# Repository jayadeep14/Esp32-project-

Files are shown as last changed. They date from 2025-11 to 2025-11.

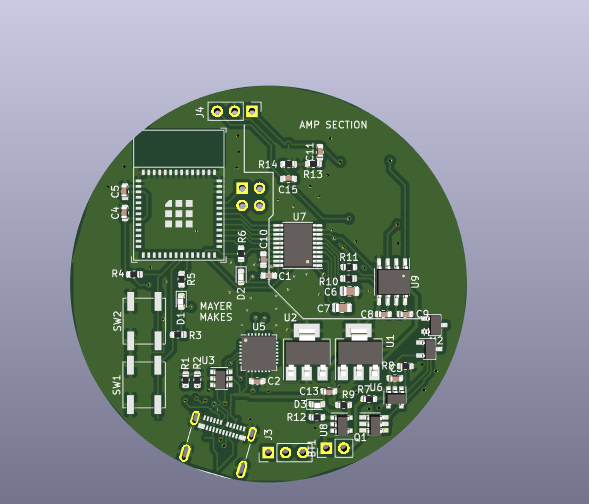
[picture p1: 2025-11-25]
Screenshot from 2025-11-24 19-12-08.png

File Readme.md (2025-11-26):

# ESP32 Bluetooth speaker



## Custom ESP32 Bluetooth speaker 
Creating a custom bluetooth speaker using esp32.Esp32 for bluetooth connectivity , a DAC (Digital-to-Analog Converter) for audio quality, potentially an amplifier, and a battery with a charging circuit.





[Bluetooth speaker case file](https://drive.google.com/file/d/19m-uVqZYdgPSqDJQQgZzTC6ExRgvEs1T/view?usp=drivesdk)

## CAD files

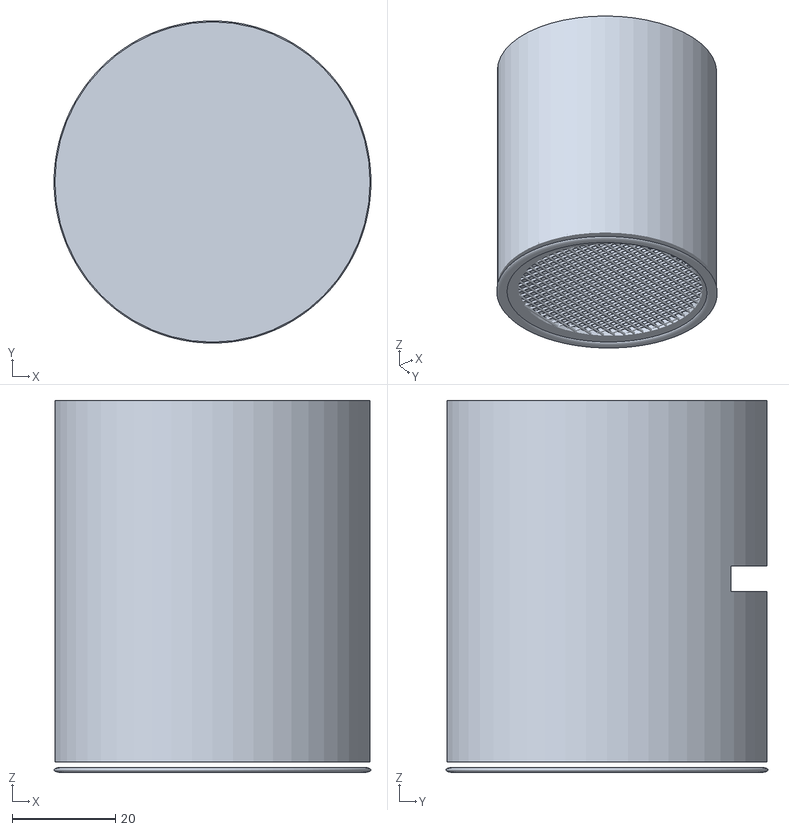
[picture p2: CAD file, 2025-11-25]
base.stl
61.3 x 62.3 x 72.0

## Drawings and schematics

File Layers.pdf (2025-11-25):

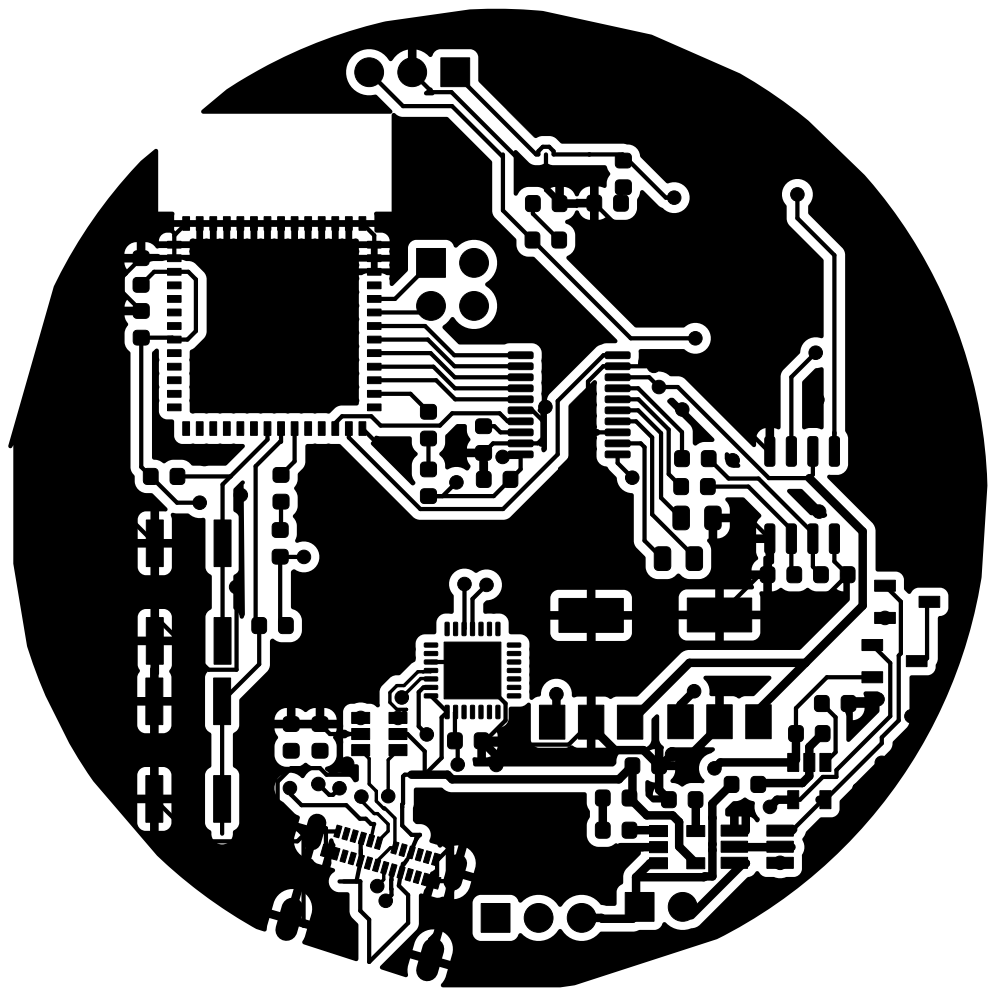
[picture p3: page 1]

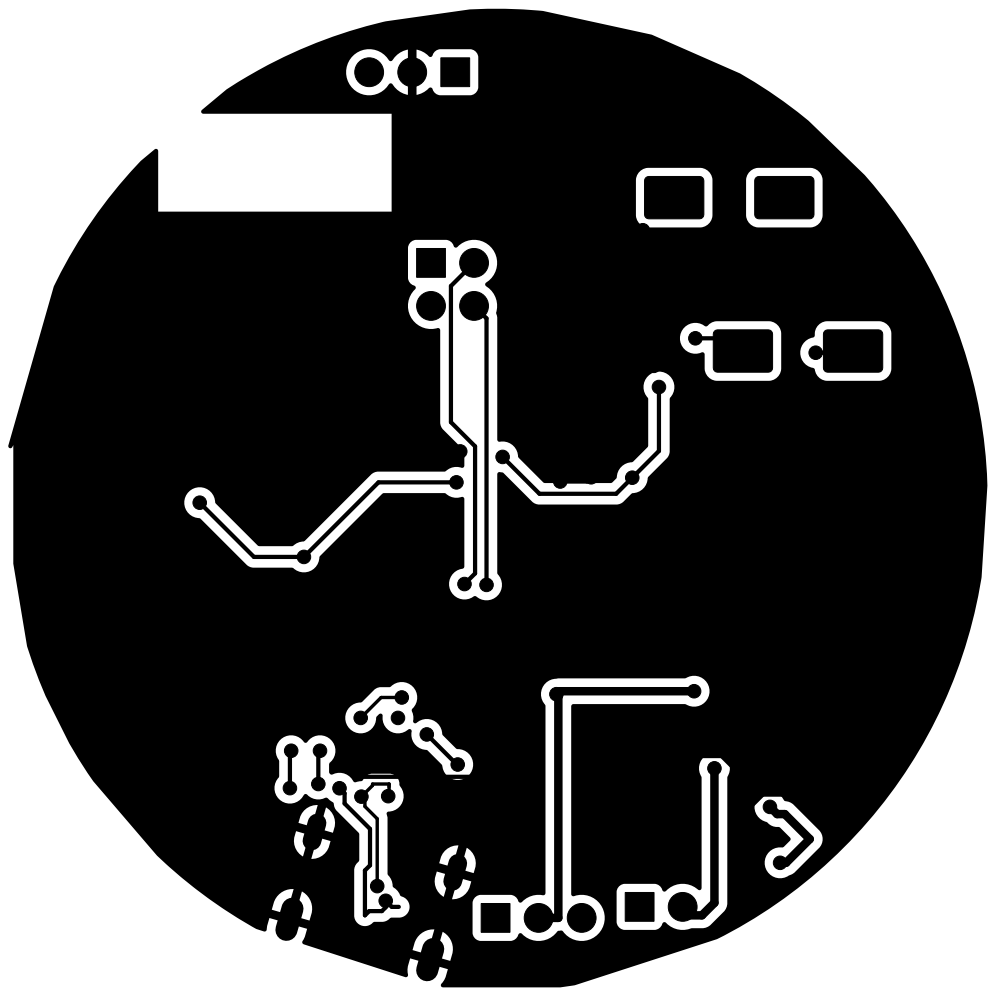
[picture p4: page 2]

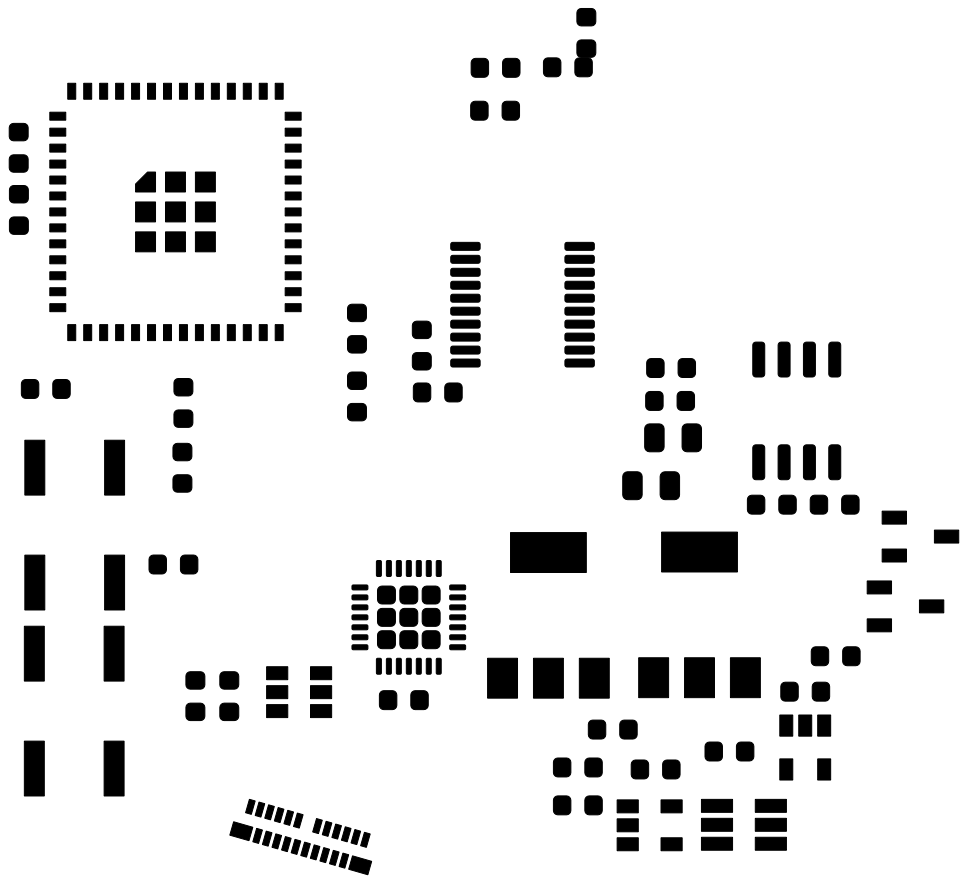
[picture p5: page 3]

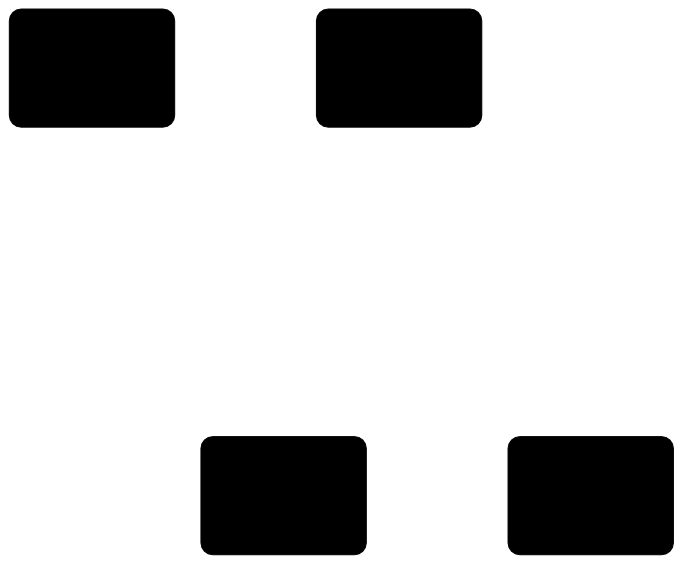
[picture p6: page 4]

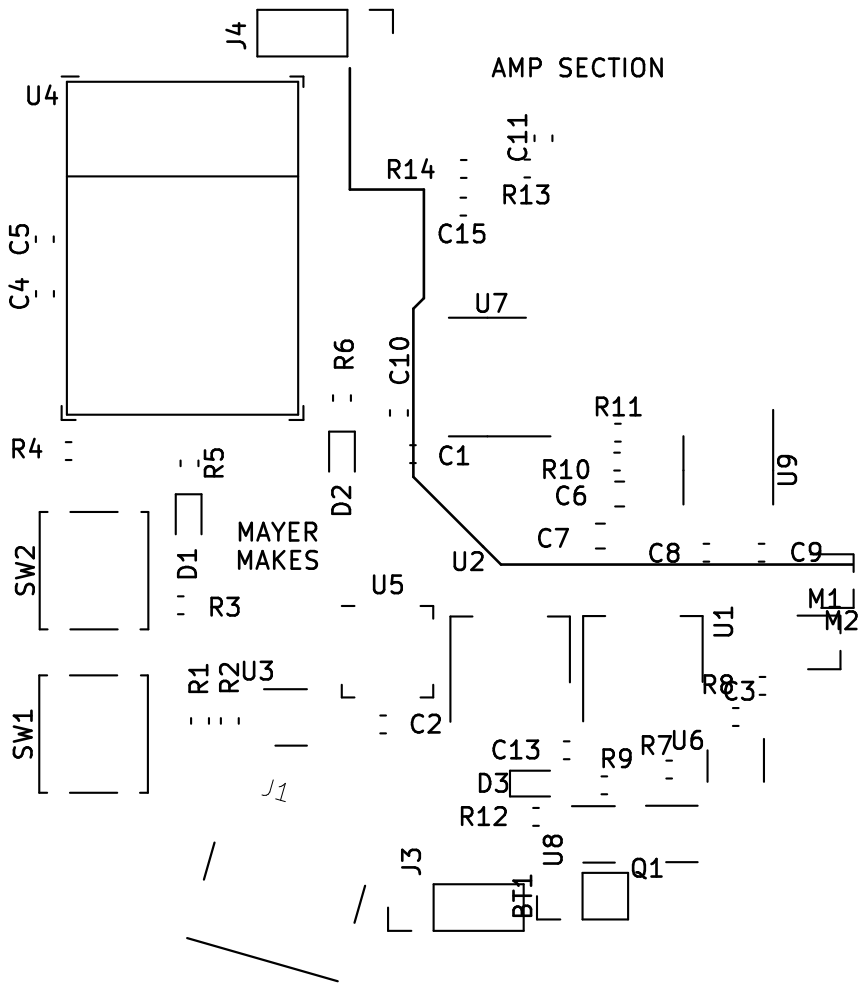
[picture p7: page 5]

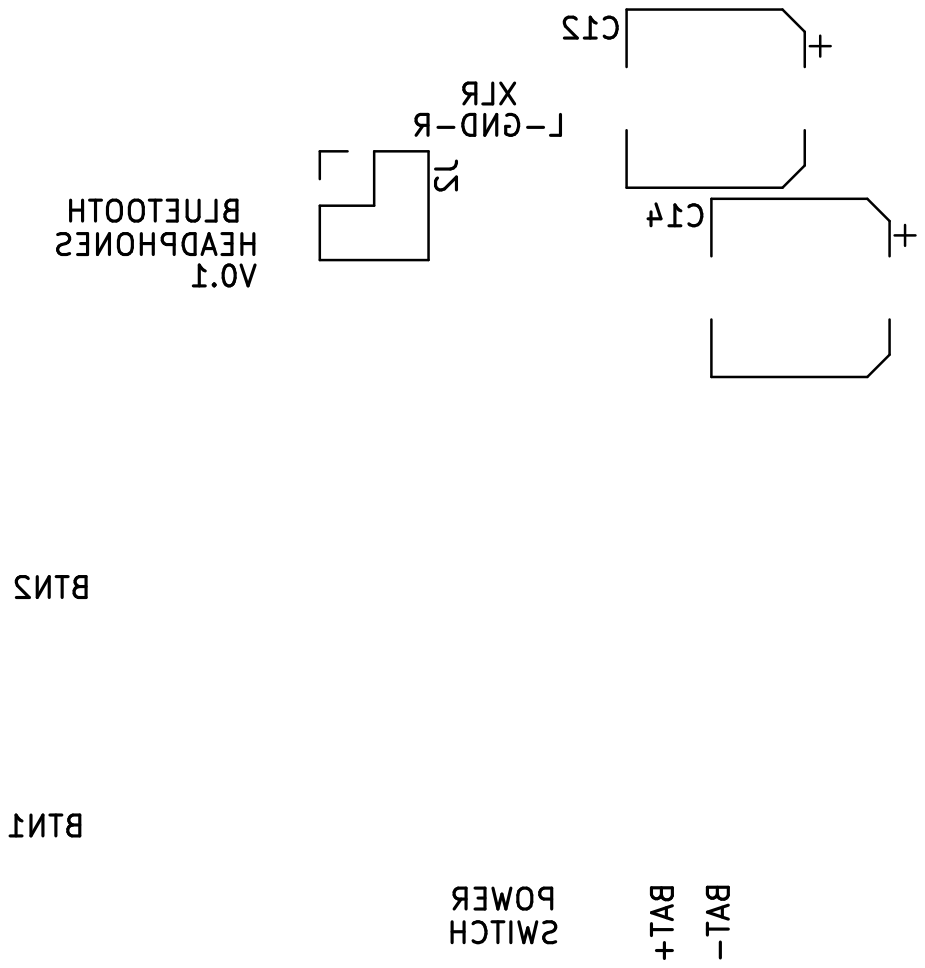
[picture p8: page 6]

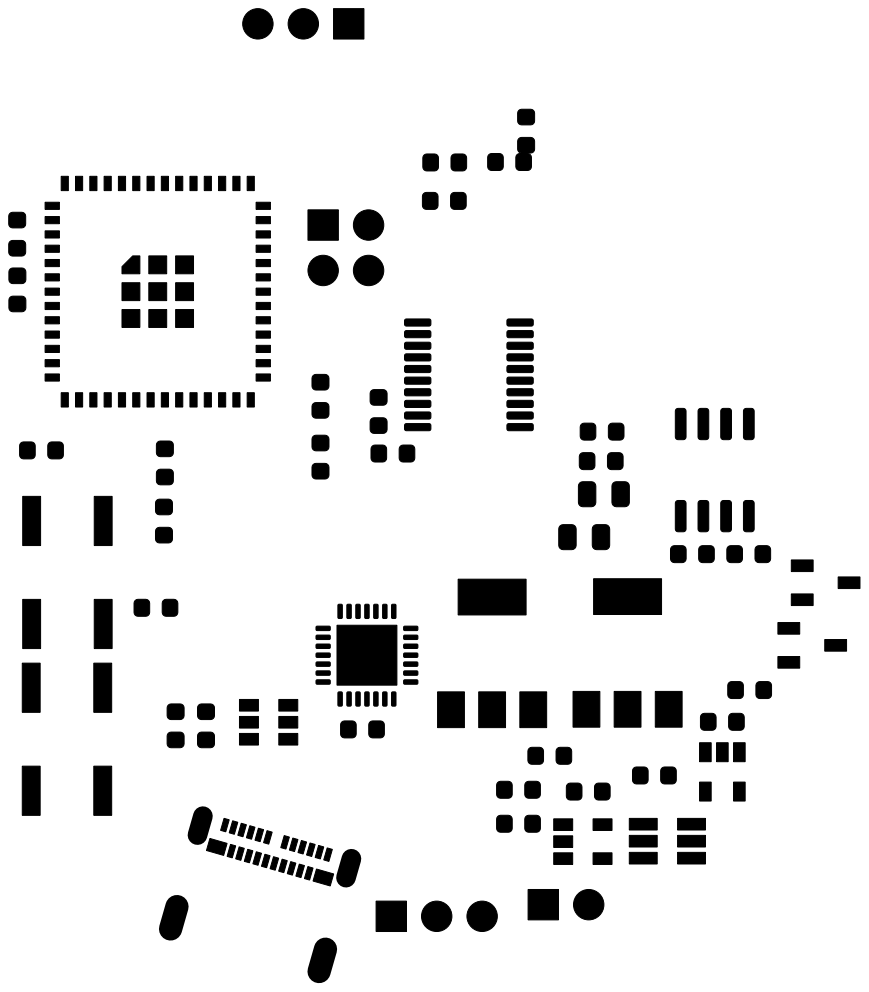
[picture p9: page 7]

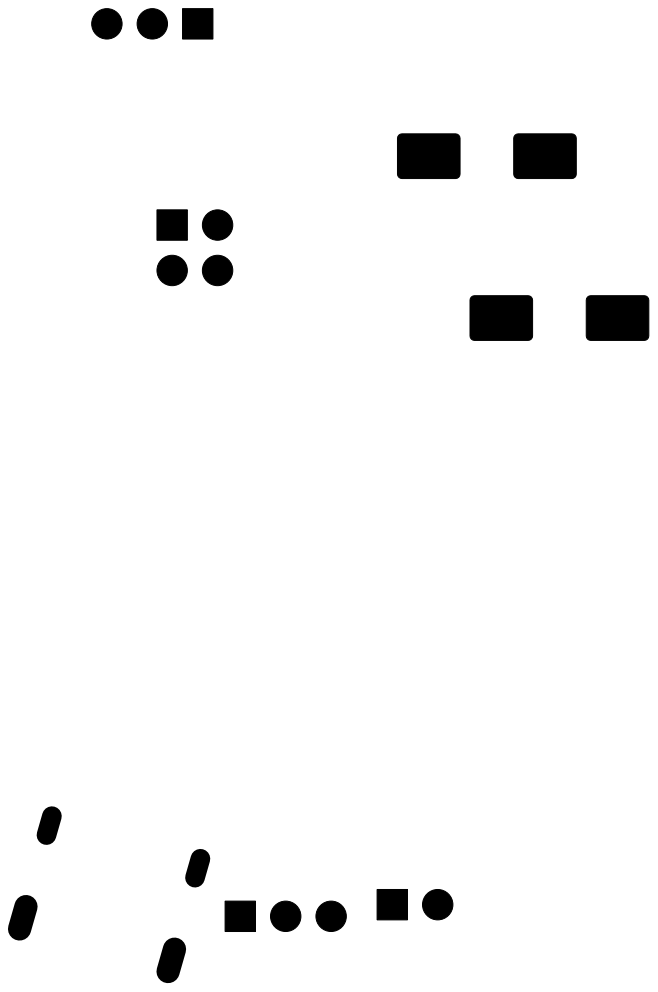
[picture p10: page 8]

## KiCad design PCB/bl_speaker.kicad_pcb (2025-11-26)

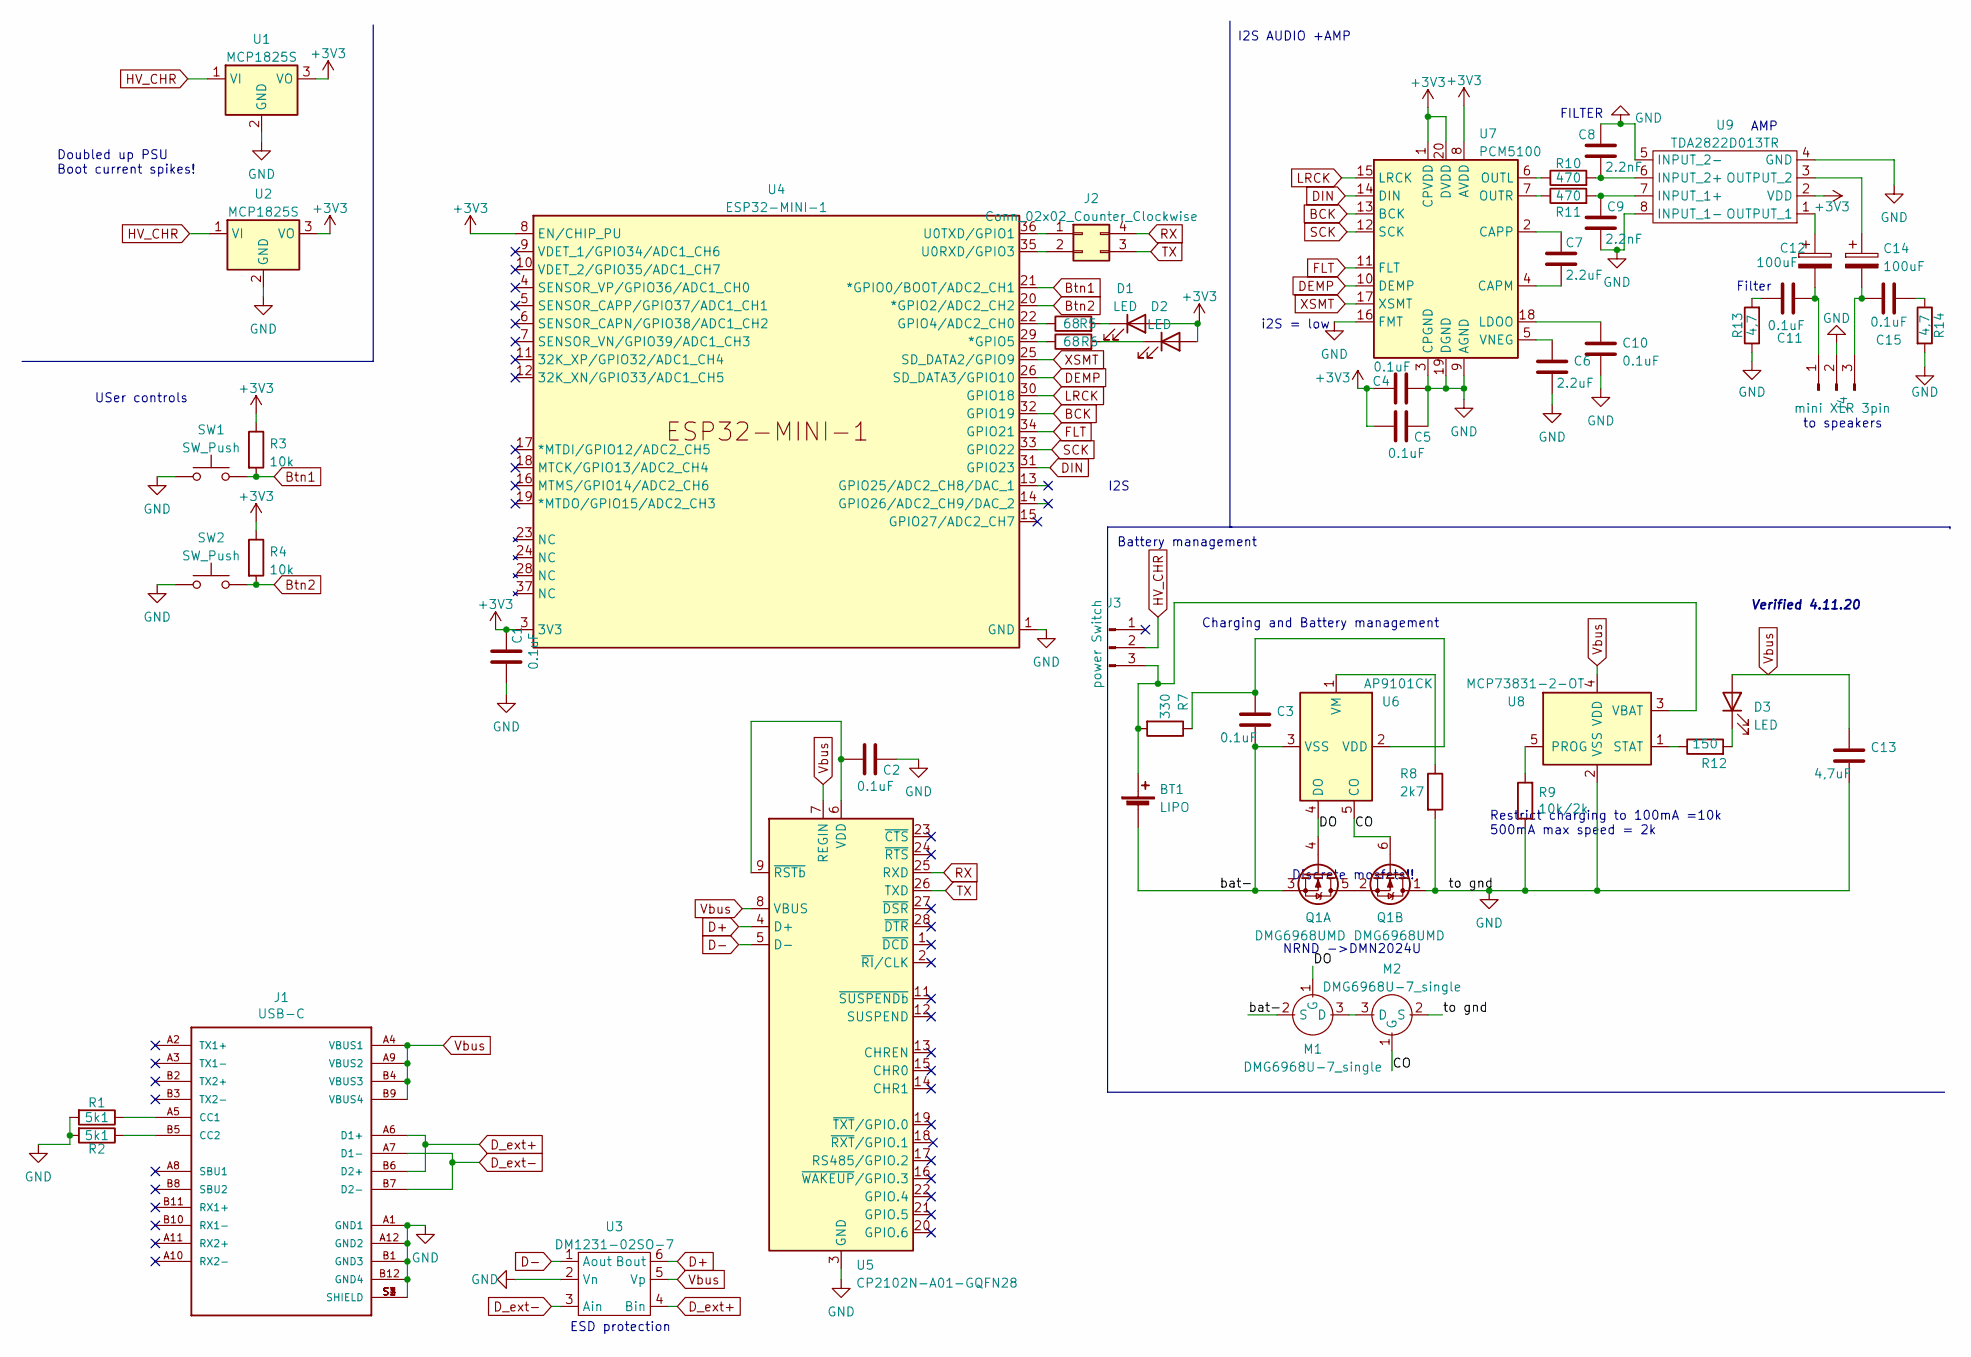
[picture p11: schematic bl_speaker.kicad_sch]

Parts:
BT1: LIPO; PinHeader_1x02_P2.54mm_Vertical
C1, C2, C3, C4, C5, C10, C11, C15: 0.1uF; C_0603_1608Metric
C6, C7: 2.2uF; C_0805_2012Metric
C8, C9: 2.2nF; C_0603_1608Metric
C12, C14: 100uF; CP_Elec_8x10
C13: 4,7uF; C_0603_1608Metric
D1, D2, D3: LED; LED_0603_1608Metric
J1: USB-C; MOLEX_105450-0101
J2: Conn_02x02_Counter_Clockwise; PinHeader_2x02_P2.54mm_Vertical
J3: power Switch; PinHeader_1x03_P2.54mm_Vertical
J4: mini XLR 3pin; PinHeader_1x03_P2.54mm_Vertical
M1, M2: DMG6968U-7_single; TSOT-23
Q1: DMG6968UMD; SOT-23-6_Handsoldering
R1, R2: 5k1; R_0603_1608Metric
R3, R4: 10k; R_0603_1608Metric
R5, R6: 68; R_0603_1608Metric
R7: 330; R_0603_1608Metric
R8: 2k7; R_0603_1608Metric
R9: 10k/2k; R_0603_1608Metric
R10, R11: 470; R_0603_1608Metric
R12: 150; R_0603_1608Metric
R13, R14: 4,7; R_0603_1608Metric
SW1, SW2: SW_Push; SW_SPST_EVQP0
U1, U2: MCP1825S; SOT-223-3_TabPin2
U3: DM1231-02SO-7; SOT-23-6
U4: ESP32-MINI-1
U5: CP2102N-A01-GQFN28; QFN-28-1EP_5x5mm_P0.5mm_EP3.35x3.35mm
U6: AP9101CK; SOT-23-5
U7: PCM5100; TSSOP-20_4.4x6.5mm_P0.65mm
U8: MCP73831-2-OT; SOT-23-5
U9: TDA2822D013TR; SO-8_3.9x4.9mm_P1.27mm

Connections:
+3V3: C1.2, C4.1, C5.1, D1.2 (A), D2.2 (A), R3.1, R4.1, U1.3 (VO), U2.3 (VO), U4.3 (3V3), U4.8 (EN/CHIP_PU), U7.1 (CPVDD), U7.8 (AVDD), U7.20 (DVDD), U9.2 (VDD)
/CO: M2.1 (G), Q1.6 (G), U6.5 (CO)
/DO: M1.1 (G), Q1.4 (G), U6.4 (DO)
/bat-: BT1.2 (-), C3.2, M1.2 (S), Q1.3 (S), U6.3 (VSS)
BCK: U4.32 (GPIO19), U7.13 (BCK)
Btn1: R3.2, SW1.2, U4.21 (*GPIO0/BOOT/ADC2_CH1)
Btn2: R4.2, SW2.2, U4.20 (*GPIO2/ADC2_CH2)
D+: U3.6 (Bout), U5.4 (D+)
D-: U3.1 (Aout), U5.5 (D-)
DEMP: U4.26 (SD_DATA3/GPIO10), U7.10 (DEMP)
DIN: U4.31 (GPIO23), U7.14 (DIN)
D_ext+: J1.A6 (D1+), J1.B6 (D2+), U3.4 (Bin)
D_ext-: J1.A7 (D1-), J1.B7 (D2-), U3.3 (Ain)
FLT: U4.34 (GPIO21), U7.11 (FLT)
GND: C1.1, C2.2, C4.2, C5.2, C6.2, C8.1, C9.2, C10.2, C13.2, J1.A1 (GND1), J1.A12 (GND2), J1.B1 (GND3), J1.B12 (GND4), J1.S1 (SHIELD), J1.S2 (SHIELD), J1.S3 (SHIELD), J1.S4 (SHIELD), J4.2, M2.2 (S), Q1.1 (D), R1.2, R2.2, R8.2, R9.1, R13.1, R14.2, SW1.1, SW2.1, U1.2 (GND), U2.2 (GND), U3.2 (Vn), U4.1 (GND), U4.2 (GND), U4.27 (GND), U4.38 (GND), U4.39 (GND), U4.40 (GND), U4.41 (GND), U4.42 (GND), U4.43 (GND), U4.44 (GND), U4.45 (GND), U4.46 (GND), U4.47 (GND), U4.48 (GND), U4.49 (GND), U4.50 (GND), U4.51 (GND), U4.52 (GND), U4.53 (GND), U4.54 (GND), U4.55 (GND), U5.3 (GND), U5.29 (GND), U7.3 (CPGND), U7.9 (AGND), U7.16 (FMT), U7.19 (DGND), U8.2 (VSS), U9.4 (GND), U9.5 (INPUT_2-), U9.8 (INPUT_1-)
HV_CHR: J3.2, U1.1 (VI), U2.1 (VI)
LRCK: U4.30 (GPIO18), U7.15 (LRCK)
unnamed: BT1.1 (+), J3.3, R7.2, U8.3 (VBAT)
unnamed: C2.1, U5.6 (VDD), U5.9 (~RSTb)
unnamed: C3.1, R7.1, U6.2 (VDD)
unnamed: C6.1, U7.5 (VNEG)
unnamed: C7.1, U7.2 (CAPP)
unnamed: C7.2, U7.4 (CAPM)
unnamed: C8.2, R10.2, U9.6 (INPUT_2+)
unnamed: C9.1, R11.2, U9.7 (INPUT_1+)
unnamed: C10.1, U7.18 (LDOO)
unnamed: C11.1, C12.2, J4.1
unnamed: C11.2, R13.2
unnamed: C12.1, U9.1 (OUTPUT_1)
unnamed: C14.1, U9.3 (OUTPUT_2)
unnamed: C14.2, C15.1, J4.3
unnamed: C15.2, R14.1
unnamed: D1.1 (K), R5.2
unnamed: D2.1 (K), R6.2
unnamed: D3.1 (K), R12.2
unnamed: J1.A5 (CC1), R1.1
unnamed: J1.B5 (CC2), R2.1
unnamed: J2.1, U4.36 (U0TXD/GPIO1)
unnamed: J2.2, U4.35 (U0RXD/GPIO3)
unnamed: M1.3 (D), M2.3 (D)
unnamed: Q1.2 (S), Q1.5 (D)
unnamed: R5.1, U4.22 (GPIO4/ADC2_CH0)
unnamed: R6.1, U4.29 (*GPIO5)
unnamed: R8.1, U6.1 (VM)
unnamed: R9.2, U8.5 (PROG)
unnamed: R10.1, U7.6 (OUTL)
unnamed: R11.1, U7.7 (OUTR)
unnamed: R12.1, U8.1 (STAT)
RX: J2.4, U5.25 (RXD)
SCK: U4.33 (GPIO22), U7.12 (SCK)
TX: J2.3, U5.26 (TXD)
Vbus: C13.1, D3.2 (A), J1.A4 (VBUS1), J1.A9 (VBUS2), J1.B4 (VBUS3), J1.B9 (VBUS4), U3.5 (Vp), U5.7 (REGIN), U5.8 (VBUS), U8.4 (VDD)
XSMT: U4.25 (SD_DATA2/GPIO9), U7.17 (XSMT)

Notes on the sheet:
I2S
Doubled up PSU Boot current spikes!
ESD protection
Battery management
FILTER
I2S AUDIO +AMP
Charging and Battery management
NRND ->DMN2024U
AMP
Verified 4.11.20
Filter
i2S = low
Restrict charging to 100mA =10k 500mA max speed = 2k
Discrete mosfets!!
to speakers
USer controls

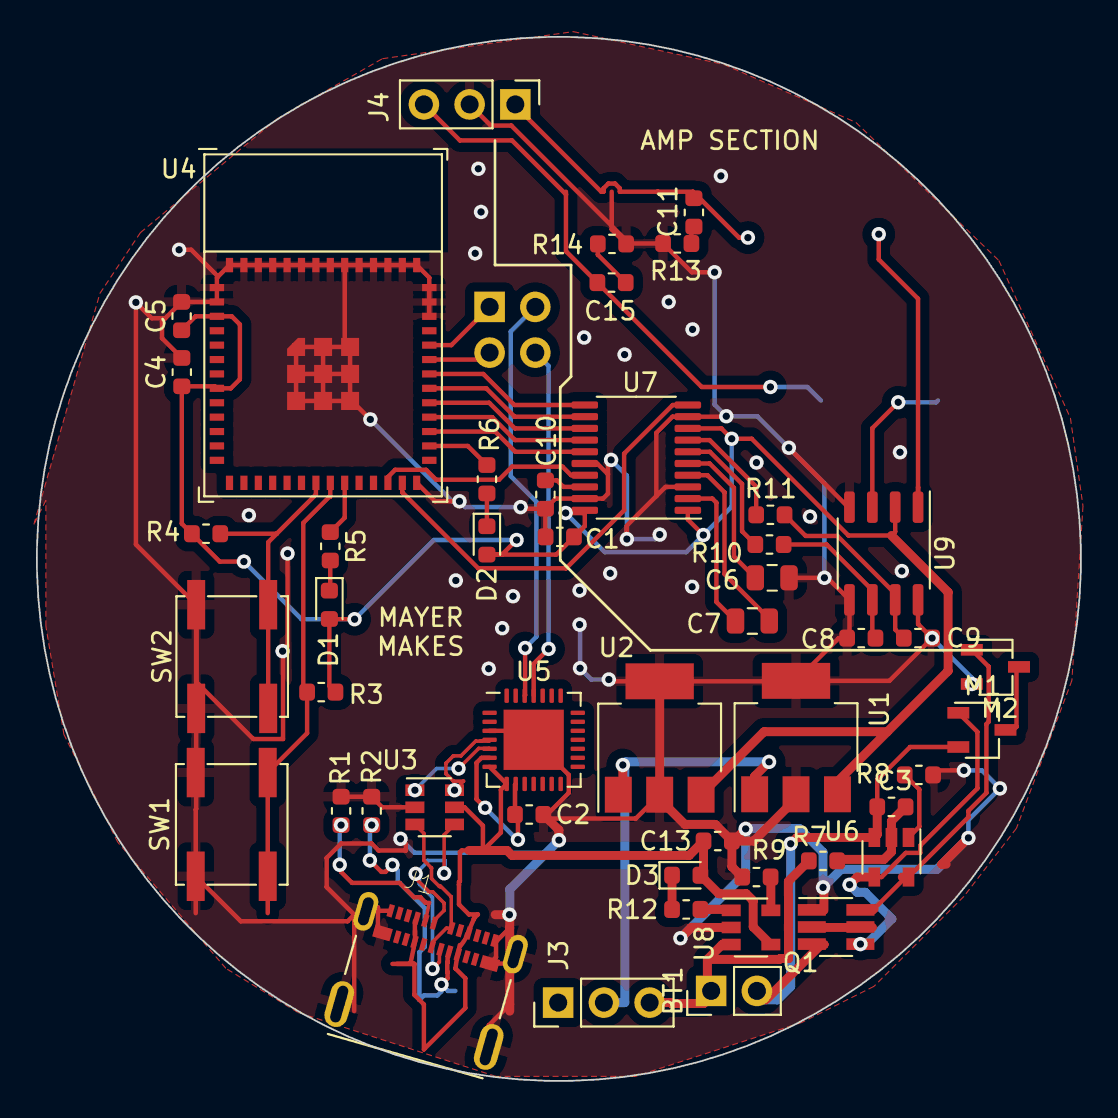
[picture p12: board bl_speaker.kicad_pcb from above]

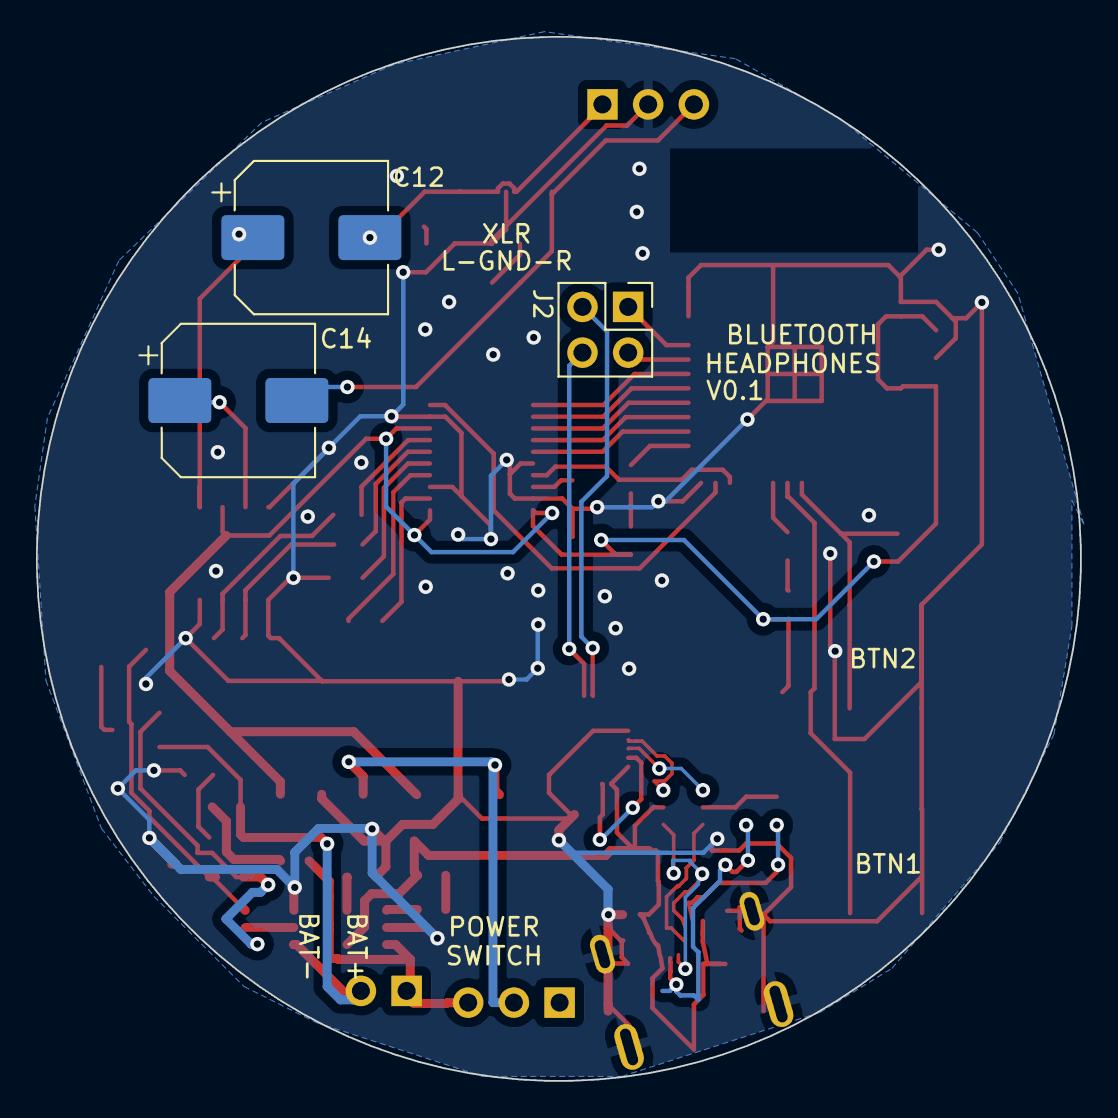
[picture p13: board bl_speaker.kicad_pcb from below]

Board: 2 copper layers, 58.0 x 58.0 mm, 51 parts (3 on the bottom side), 53 nets.

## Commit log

2025-11-25 Add initial README for Esp32 project
2025-11-25 Rename Bt_speaker/gerber (1).zip to Bt_speaker/PCB/gerber (1).zip
2025-11-25 Add link to Bluetooth speaker case file in README
    Added a link to the Bluetooth speaker case file.
2025-11-26 Enhance README with images and project details
    Added images and improved description for the ESP32 Bluetooth speaker project.
